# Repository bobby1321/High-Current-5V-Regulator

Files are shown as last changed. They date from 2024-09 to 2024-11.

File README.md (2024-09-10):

# High Current 5V DC Buck Converter Board
This board is a high current (8A) buck converter based around the TPS51386 for providing USB power to multiple devices from one board. Focused around working from a 4S Lithium Ion battery, it should work for any input voltage source from 10V-26V DC. The board also incorporates two INA219A PMICs for monitoring input & output power over I2C.

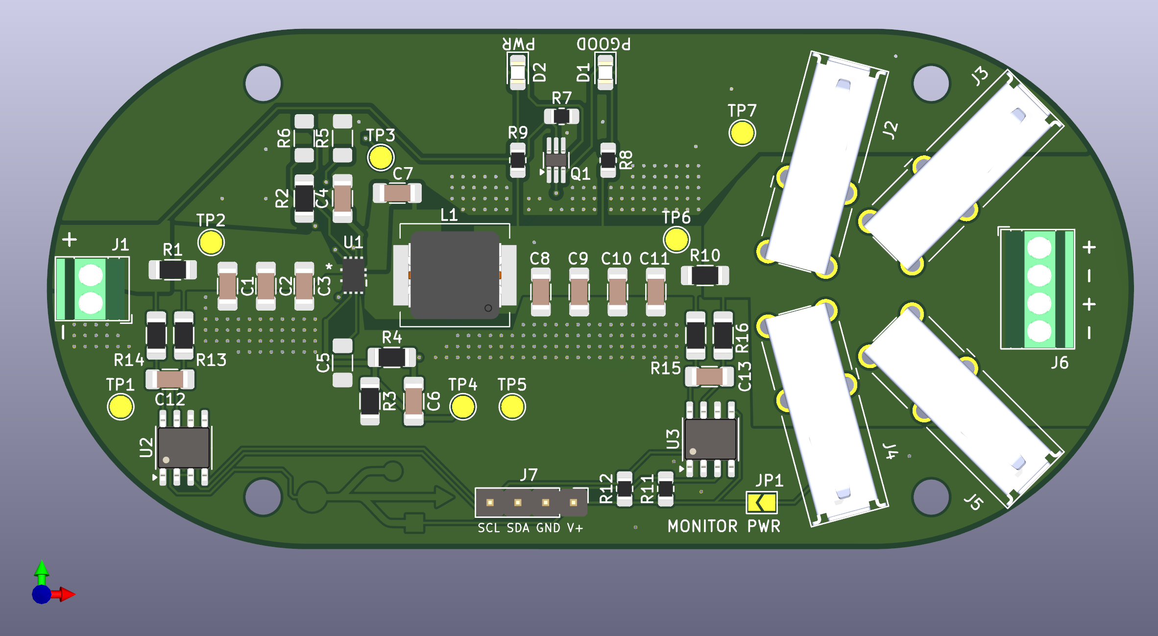
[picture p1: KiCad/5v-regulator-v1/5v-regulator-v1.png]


Also included in this repo is a small 4S Li-Ion battery voltage meter.

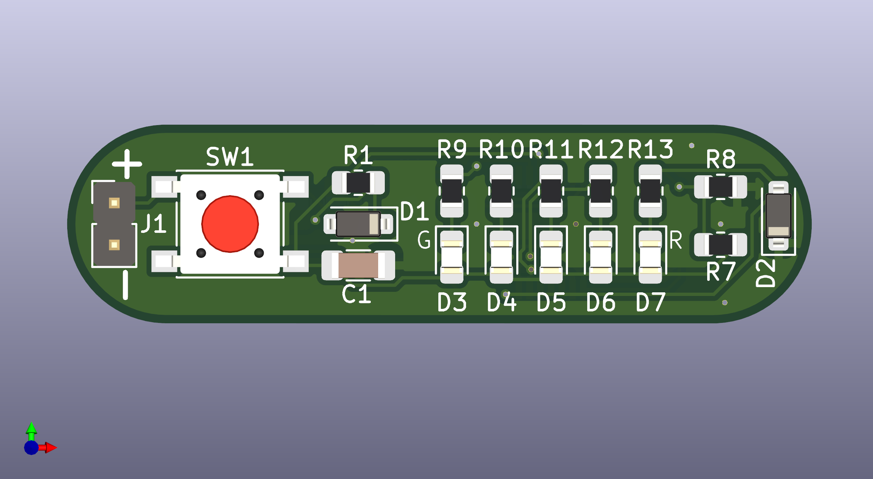
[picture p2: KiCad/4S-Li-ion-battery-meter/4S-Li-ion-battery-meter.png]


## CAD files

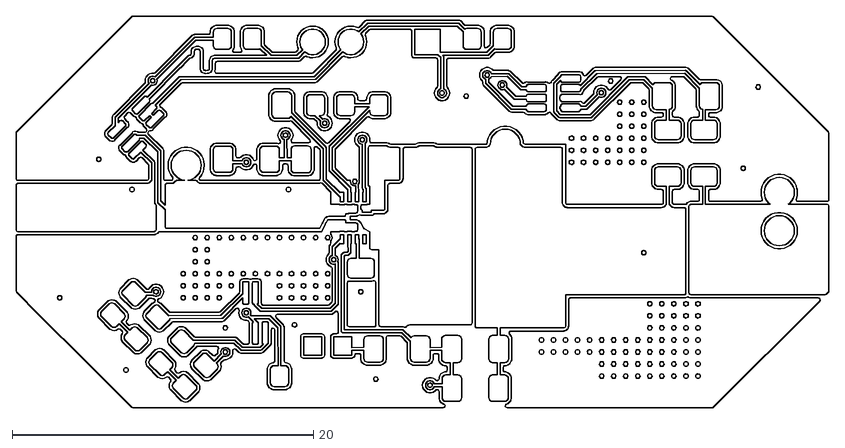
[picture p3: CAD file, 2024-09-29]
KiCad/5v-regulator-v2/5v-regulator-v2-F_Cu.dxf
54.0 x 26.0

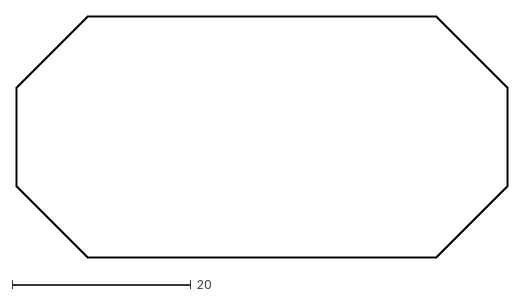
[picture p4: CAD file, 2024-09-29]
KiCad/5v-regulator-v2/5v-regulator-v2-Edge_Cuts.dxf
55.0 x 27.0

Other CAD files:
KiCad/5v-regulator-v2/5v-regulator-v2-F_Silkscreen.dxf

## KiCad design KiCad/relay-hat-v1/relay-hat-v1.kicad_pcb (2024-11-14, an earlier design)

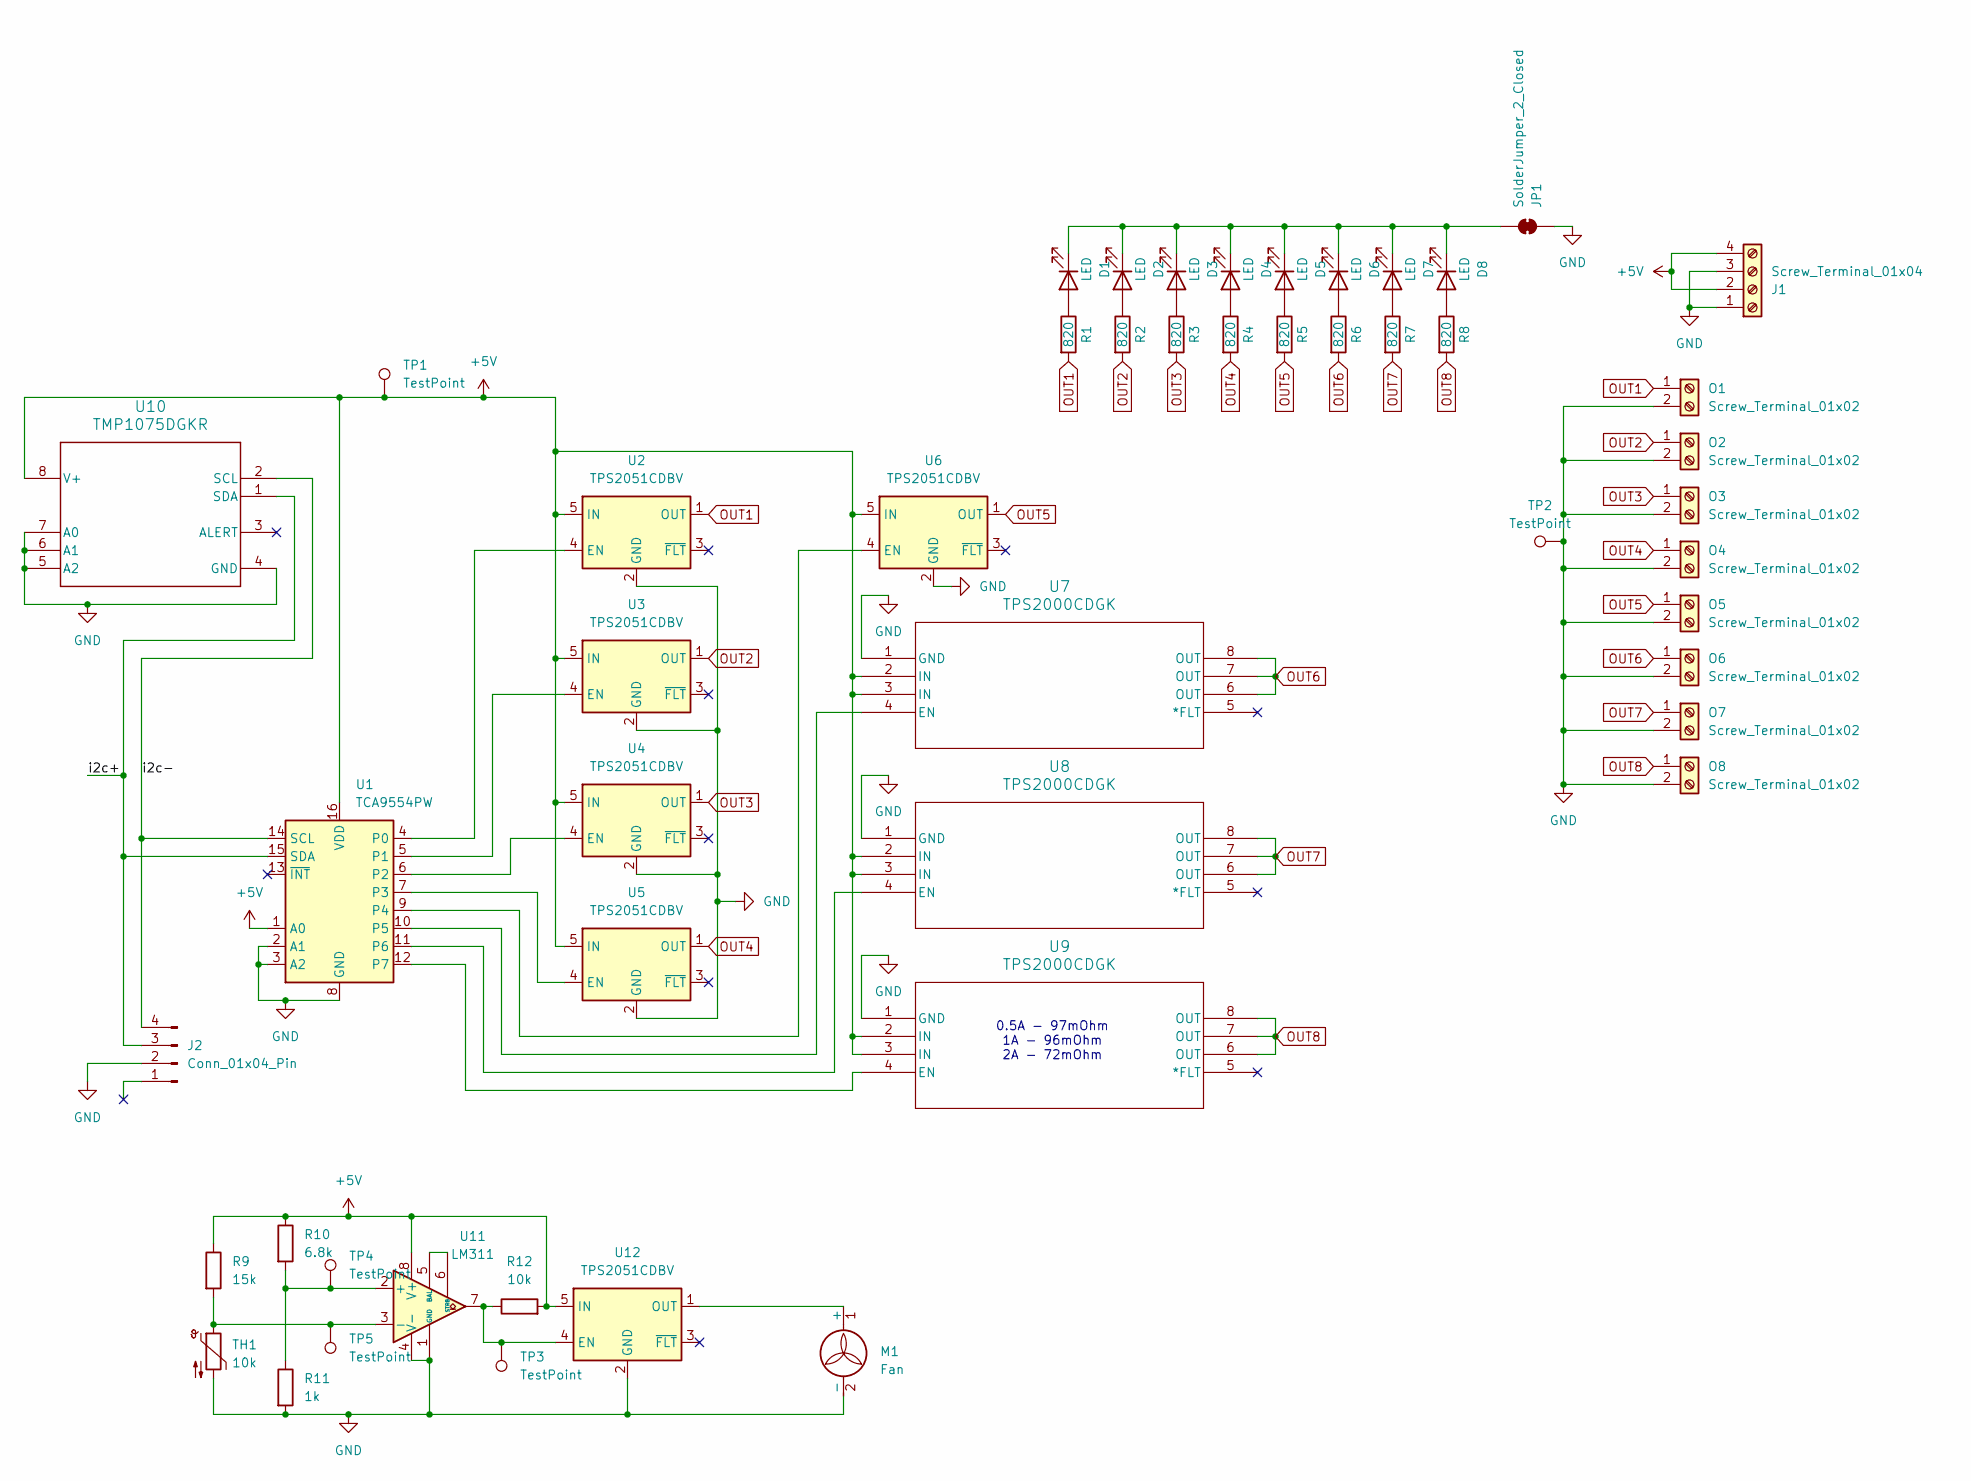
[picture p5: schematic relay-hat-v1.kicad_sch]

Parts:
D1, D2, D3, D4, D5, D6, D7, D8: LED; LED_0805_2012Metric_Pad1.15x1.40mm_HandSolder
J1: Screw_Terminal_01x04; TerminalBlock_Phoenix_MPT-0,5-4-2.54_1x04_P2.54mm_Horizontal
J2: Conn_01x04_Pin; PinHeader_1x04_P2.54mm_Vertical
JP1: SolderJumper_2_Closed; SolderJumper-2_P1.3mm_Open_TrianglePad1.0x1.5mm
M1: Fan; JST_XH_B2B-XH-A_1x02_P2.50mm_Vertical
O1, O2, O3, O4, O5, O6, O7, O8: Screw_Terminal_01x02; TerminalBlock_Phoenix_MPT-0,5-2-2.54_1x02_P2.54mm_Horizontal
R1, R2, R3, R4, R5, R6, R7, R8: 820; R_0805_2012Metric_Pad1.20x1.40mm_HandSolder
R9: 15k; R_0805_2012Metric_Pad1.20x1.40mm_HandSolder
R10: 6.8k; R_0805_2012Metric_Pad1.20x1.40mm_HandSolder
R11: 1k; R_0805_2012Metric_Pad1.20x1.40mm_HandSolder
R12: 10k; R_0805_2012Metric_Pad1.20x1.40mm_HandSolder
TH1: 10k; JST_XH_B2B-XH-A_1x02_P2.50mm_Vertical
TP1, TP2, TP3, TP4, TP5: TestPoint; TestPoint_Pad_D1.0mm
U1: TCA9554PW; TSSOP-16_4.4x5mm_P0.65mm
U2, U3, U4, U5, U6, U12: TPS2051CDBV; SOT-23-5
U7, U8, U9: TPS2000CDGK; DGK8
U10: TMP1075DGKR; DGK0008A_N
U11: LM311; SOIC-8_3.9x4.9mm_P1.27mm

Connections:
+5V: J1.2, J1.4, R9.1, R10.1, R12.2, TP1.1, U1.1 (A0), U1.16 (VDD), U2.5 (IN), U3.5 (IN), U4.5 (IN), U5.5 (IN), U6.5 (IN), U7.2 (IN), U7.3 (IN), U8.2 (IN), U8.3 (IN), U9.2 (IN), U9.3 (IN), U10.8 (V+), U11.8 (V+), U12.5 (IN)
/i2c+: J2.3, U1.15 (SDA), U10.1 (SDA)
/i2c-: J2.4, U1.14 (SCL), U10.2 (SCL)
GND: J1.1, J1.3, J2.2, JP1.2 (B), M1.2 (-), O1.2, O2.2, O3.2, O4.2, O5.2, O6.2, O7.2, O8.2, R11.2, TH1.2, TP2.1, U1.2 (A1), U1.3 (A2), U1.8 (GND), U2.2 (GND), U3.2 (GND), U4.2 (GND), U5.2 (GND), U6.2 (GND), U7.1 (GND), U8.1 (GND), U9.1 (GND), U10.4 (GND), U10.5 (A2), U10.6 (A1), U10.7 (A0), U11.1 (GND), U11.4 (V-), U12.2 (GND)
unnamed: D1.2 (A), R1.1
unnamed: D1.1 (K), D2.1 (K), D3.1 (K), D4.1 (K), D5.1 (K), D6.1 (K), D7.1 (K), D8.1 (K), JP1.1 (A)
unnamed: D2.2 (A), R2.1
unnamed: D3.2 (A), R3.1
unnamed: D4.2 (A), R4.1
unnamed: D5.2 (A), R5.1
unnamed: D6.2 (A), R6.1
unnamed: D7.2 (A), R7.1
unnamed: D8.2 (A), R8.1
unnamed: M1.1 (+), U12.1 (OUT)
unnamed: U1.4 (P0), U2.4 (EN)
unnamed: U1.5 (P1), U3.4 (EN)
unnamed: U1.6 (P2), U4.4 (EN)
unnamed: U1.7 (P3), U5.4 (EN)
unnamed: U1.9 (P4), U6.4 (EN)
unnamed: U1.10 (P5), U7.4 (EN)
unnamed: U1.11 (P6), U8.4 (EN)
unnamed: U1.12 (P7), U9.4 (EN)
unnamed: R10.2, R11.1, TP4.1, U11.2 (+)
unnamed: R9.2, TH1.1, TP5.1, U11.3 (-)
unnamed: U11.5 (BAL), U11.6 (STRB)
unnamed: R12.1, TP3.1, U11.7, U12.4 (EN)
OUT1: O1.1, R1.2, U2.1 (OUT)
OUT2: O2.1, R2.2, U3.1 (OUT)
OUT3: O3.1, R3.2, U4.1 (OUT)
OUT4: O4.1, R4.2, U5.1 (OUT)
OUT5: O5.1, R5.2, U6.1 (OUT)
OUT6: O6.1, R6.2, U7.6 (OUT), U7.7 (OUT), U7.8 (OUT)
OUT7: O7.1, R7.2, U8.6 (OUT), U8.7 (OUT), U8.8 (OUT)
OUT8: O8.1, R8.2, U9.6 (OUT), U9.7 (OUT), U9.8 (OUT)

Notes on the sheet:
0.5A - 97mOhm 1A - 96mOhm 2A - 72mOhm

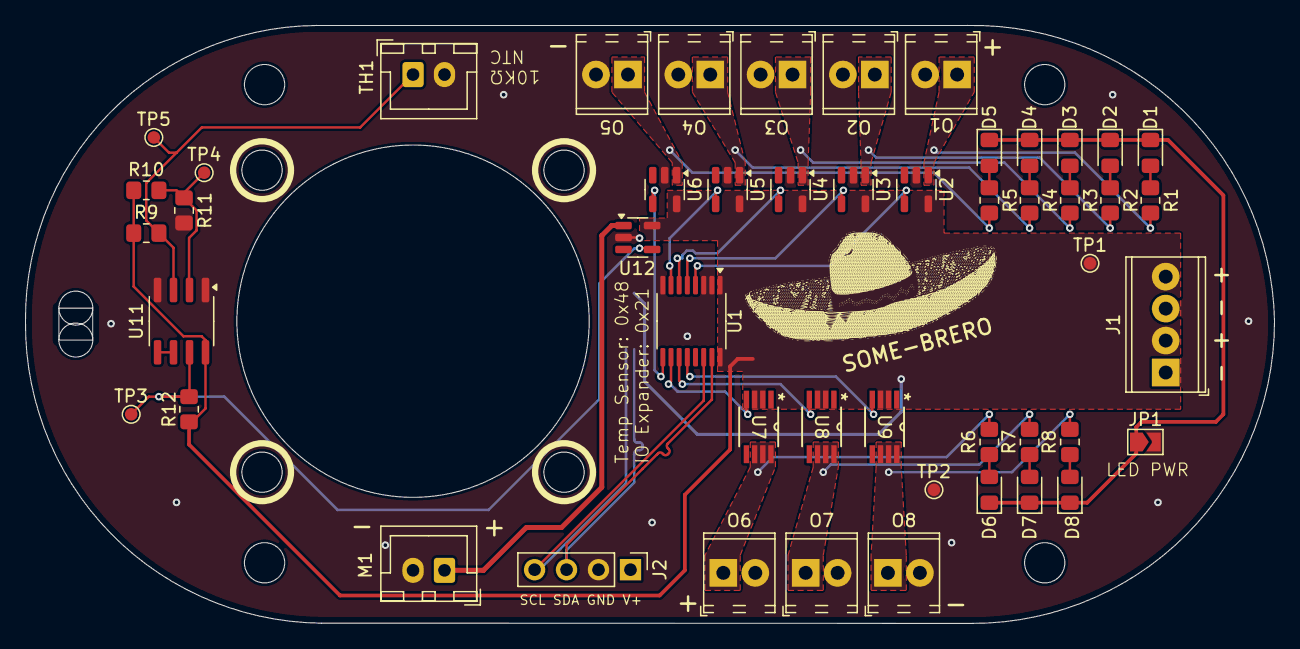
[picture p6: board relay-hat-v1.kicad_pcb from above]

Board: 2 copper layers, 99.3 x 47.5 mm, 50 parts (1 on the bottom side), 34 nets.

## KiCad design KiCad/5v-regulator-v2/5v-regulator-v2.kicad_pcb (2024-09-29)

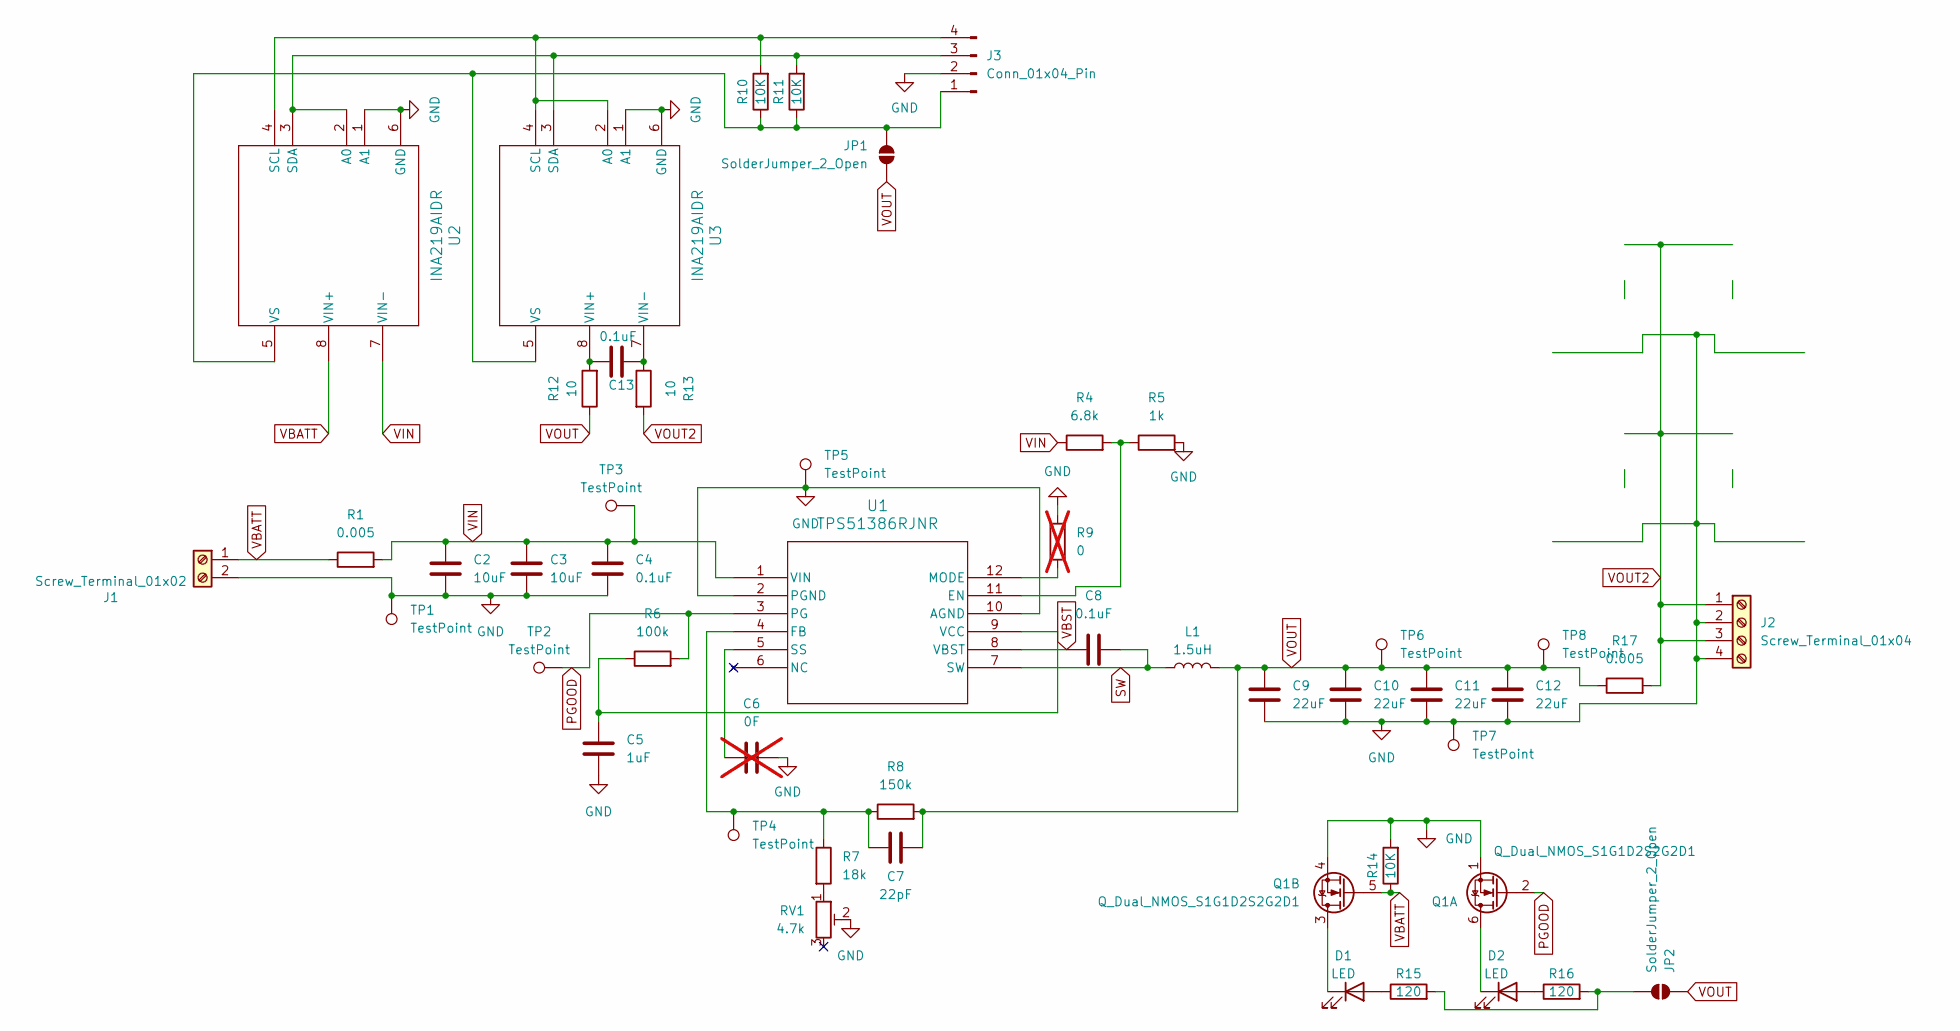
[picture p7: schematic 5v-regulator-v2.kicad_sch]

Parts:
C2, C3: 10uF; C_1206_3216Metric_Pad1.33x1.80mm_HandSolder
C4, C8, C13: 0.1uF; C_1206_3216Metric_Pad1.33x1.80mm_HandSolder
C5: 1uF; C_1206_3216Metric_Pad1.33x1.80mm_HandSolder
C6: 0F; C_1206_3216Metric_Pad1.33x1.80mm_HandSolder; not fitted
C7: 22pF; C_1206_3216Metric_Pad1.33x1.80mm_HandSolder
C9, C10, C11, C12: 22uF; C_1206_3216Metric_Pad1.33x1.80mm_HandSolder
D1, D2: LED; LED_0805_2012Metric_Pad1.15x1.40mm_HandSolder
J1: Screw_Terminal_01x02; TerminalBlock_Xinya_XY308-2.54-2P_1x02_P2.54mm_Horizontal
J2: Screw_Terminal_01x04; TerminalBlock_Xinya_XY308-2.54-4P_1x04_P2.54mm_Horizontal
J3: Conn_01x04_Pin; PinHeader_1x04_P2.54mm_Vertical
JP1, JP2: SolderJumper_2_Open; SolderJumper-2_P1.3mm_Open_TrianglePad1.0x1.5mm
L1: 1.5uH; L_Panasonic_ETQP4M---KVK
Q1: Q_Dual_NMOS_S1G1D2S2G2D1; SOT-363_SC-70-6_Handsoldering
R1, R17: 0.005; R_1206_3216Metric_Pad1.30x1.75mm_HandSolder
R4: 6.8k; R_0805_2012Metric_Pad1.20x1.40mm_HandSolder
R5: 1k; R_0805_2012Metric_Pad1.20x1.40mm_HandSolder
R6: 100k; R_1206_3216Metric_Pad1.30x1.75mm_HandSolder
R7: 18k; R_1206_3216Metric_Pad1.30x1.75mm_HandSolder
R8: 150k; R_1206_3216Metric_Pad1.30x1.75mm_HandSolder
R9: 0; R_1206_3216Metric_Pad1.30x1.75mm_HandSolder; not fitted
R10, R11, R14: 10K; R_0805_2012Metric_Pad1.20x1.40mm_HandSolder
R12, R13: 10; R_1206_3216Metric_Pad1.30x1.75mm_HandSolder
R15, R16: 120; R_0805_2012Metric_Pad1.20x1.40mm_HandSolder
RV1: 4.7k; Potentiometer_Bourns_TC33X_Vertical
TP1, TP2, TP3, TP4, TP5, TP6, TP7: TestPoint; TestPoint_Pad_D2.0mm
TP8: TestPoint; usb_symbol
U1: TPS51386RJNR; VQFN-HR12_RJN_TEX
U2, U3: INA219AIDR; SOT-23-8

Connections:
GND: C2.2, C3.2, C4.2, C5.2, C6.2, C9.2, C10.2, C11.2, C12.2, J1.2, J2.2, J2.4, J3.2, Q1.1 (S), Q1.4 (S), R5.2, R9.2, R14.2, RV1.2, TP1.1, TP5.1, TP7.1, U1.2 (PGND), U1.10 (AGND), U2.1 (A1), U2.6 (GND), U3.1 (A1), U3.6 (GND)
unnamed: D1.2 (A), R15.1
unnamed: D1.1 (K), Q1.3 (D)
unnamed: D2.2 (A), R16.1
unnamed: D2.1 (K), Q1.6 (D)
unnamed: J3.1, JP1.2 (B), R10.1, R11.1, U2.5 (VS), U3.5 (VS)
unnamed: J3.3, R11.2, U2.2 (A0), U2.3 (SDA), U3.3 (SDA)
unnamed: J3.4, R10.2, U2.4 (SCL), U3.2 (A0), U3.4 (SCL)
unnamed: JP2.1 (A), R15.2, R16.2
unnamed: R7.2, RV1.1
unnamed: R4.2, R5.1, U1.11 (EN)
unnamed: C7.2, R7.1, R8.1, TP4.1, U1.4 (FB)
unnamed: R9.1, U1.12 (MODE)
unnamed: C6.1, U1.5 (SS)
unnamed: C5.1, R6.1, U1.9 (VCC)
unnamed: C13.2, R12.2, U3.8 (VIN+)
unnamed: C13.1, R13.1, U3.7 (VIN-)
PGOOD: Q1.2 (G), R6.2, TP2.1, U1.3 (PG)
SW: C8.2, L1.1, U1.7 (SW)
VBATT: J1.1, Q1.5 (G), R1.1, R14.1, U2.8 (VIN+)
VBST: C8.1, U1.8 (VBST)
VIN: C2.1, C3.1, C4.1, R1.2, R4.1, TP3.1, U1.1 (VIN), U2.7 (VIN-)
VOUT: C7.1, C9.1, C10.1, C11.1, C12.1, JP1.1 (A), JP2.2 (B), L1.2, R8.2, R12.1, R17.1, TP6.1, TP8.1
VOUT2: J2.1, J2.3, R13.2, R17.2

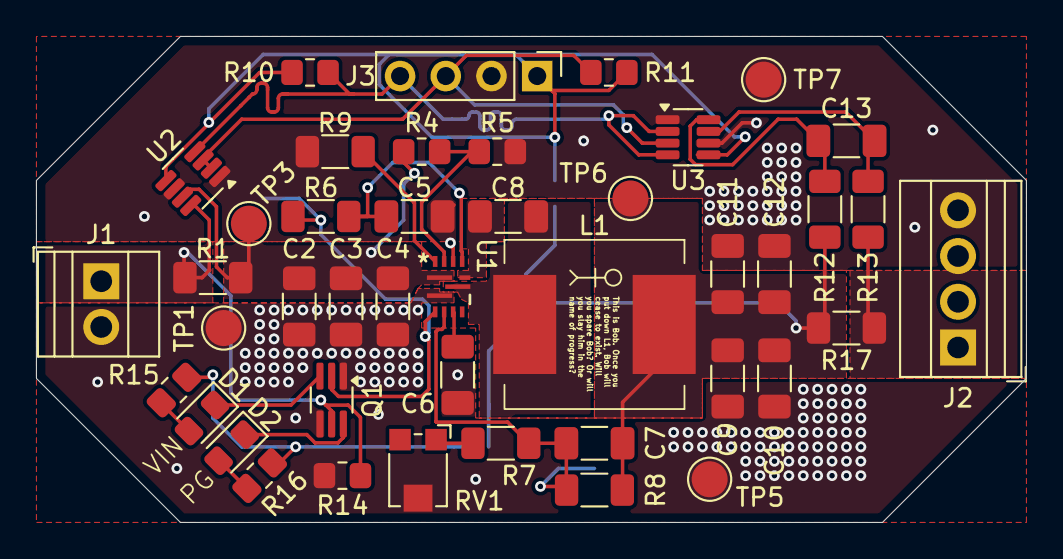
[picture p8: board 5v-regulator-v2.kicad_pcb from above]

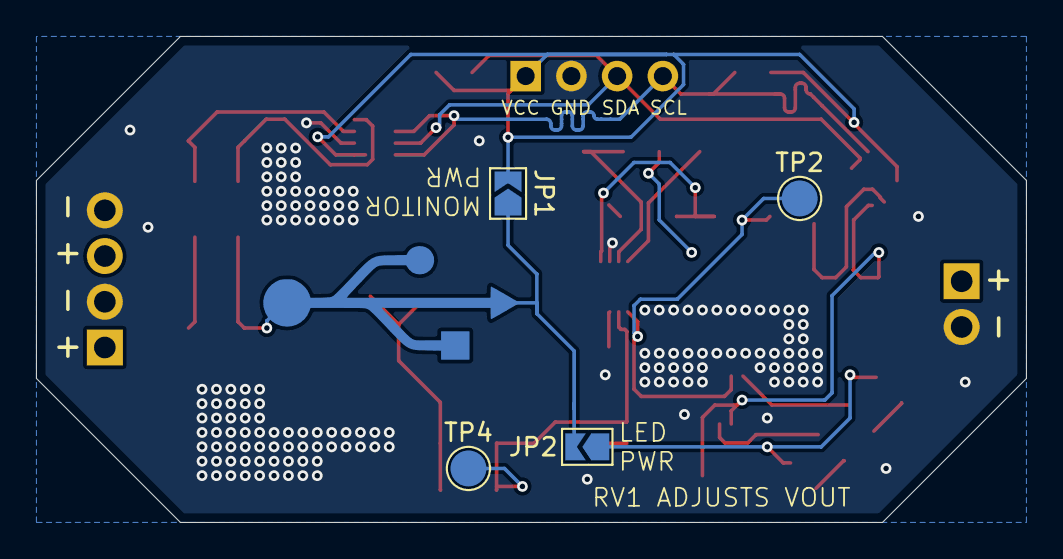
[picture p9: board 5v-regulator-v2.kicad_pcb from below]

Board: 2 copper layers, 55.0 x 27.0 mm, 48 parts (5 on the bottom side), 24 nets.

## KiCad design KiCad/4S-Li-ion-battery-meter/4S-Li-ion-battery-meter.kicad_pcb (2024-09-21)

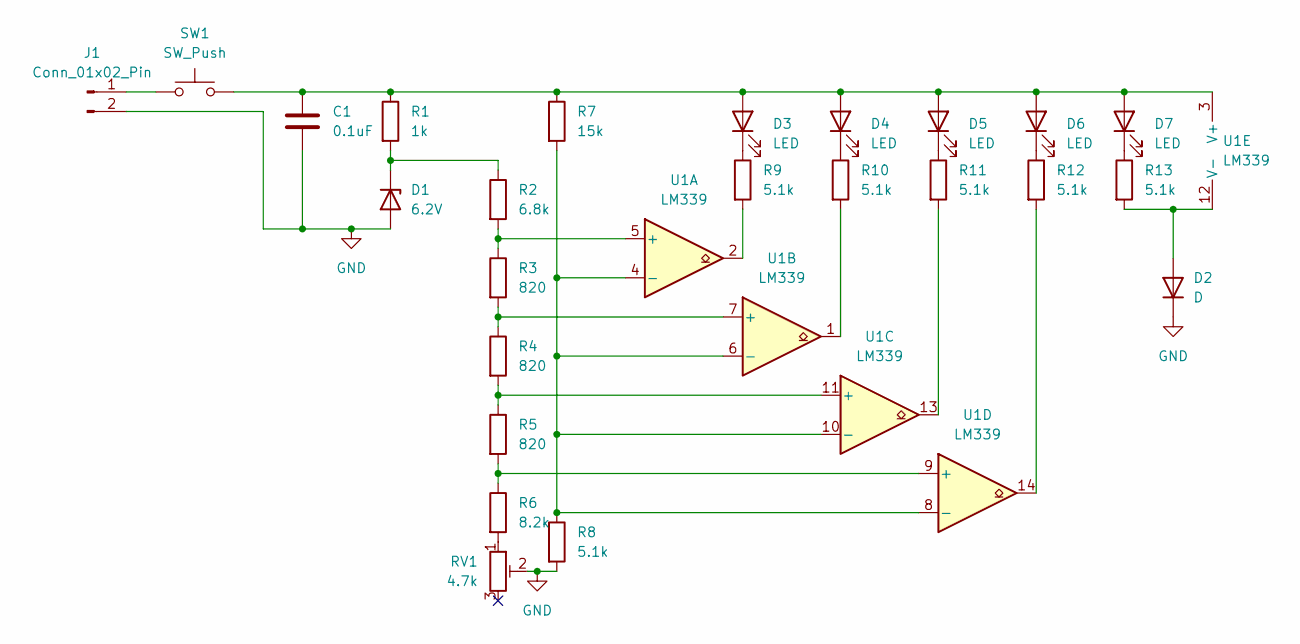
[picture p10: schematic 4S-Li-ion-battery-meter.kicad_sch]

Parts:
C1: 0.1uF; C_1206_3216Metric_Pad1.33x1.80mm_HandSolder
D1: 6.2V; D_SOD-123
D2: D; D_SOD-123
D3, D4, D5, D6, D7: LED; LED_0805_2012Metric_Pad1.15x1.40mm_HandSolder
J1: Conn_01x02_Pin; PinHeader_1x02_P2.54mm_Vertical
R1: 1k; R_0805_2012Metric_Pad1.20x1.40mm_HandSolder
R2: 6.8k; R_0805_2012Metric_Pad1.20x1.40mm_HandSolder
R3, R4, R5: 820; R_0805_2012Metric_Pad1.20x1.40mm_HandSolder
R6: 8.2k; R_0805_2012Metric_Pad1.20x1.40mm_HandSolder
R7: 15k; R_0805_2012Metric_Pad1.20x1.40mm_HandSolder
R8, R9, R10, R11, R12, R13: 5.1k; R_0805_2012Metric_Pad1.20x1.40mm_HandSolder
RV1: 4.7k; Potentiometer_Bourns_TC33X_Vertical
SW1: SW_Push; SW_Push_1P1T_NO_6x6mm_H9.5mm
U1: LM339; SSOP-14_5.3x6.2mm_P0.65mm

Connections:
GND: C1.2, D1.2 (A), D2.1 (K), J1.2, R8.2, RV1.2
unnamed: D1.1 (K), R1.2, R2.1
unnamed: D2.2 (A), R13.2, U1.12 (V-)
unnamed: C1.1, D3.2 (A), D4.2 (A), D5.2 (A), D6.2 (A), D7.2 (A), R1.1, R7.1, SW1.2, U1.3 (V+)
unnamed: D3.1 (K), R9.1
unnamed: D4.1 (K), R10.1
unnamed: D5.1 (K), R11.1
unnamed: D6.1 (K), R12.1
unnamed: D7.1 (K), R13.1
unnamed: J1.1, SW1.1
unnamed: R6.2, RV1.1
unnamed: R9.2, U1.2
unnamed: R10.2, U1.1
unnamed: R11.2, U1.13
unnamed: R12.2, U1.14
unnamed: R2.2, R3.1, U1.5 (+)
unnamed: R7.2, R8.1, U1.4 (-), U1.6 (-), U1.8 (-), U1.10 (-)
unnamed: R3.2, R4.1, U1.7 (+)
unnamed: R4.2, R5.1, U1.11 (+)
unnamed: R5.2, R6.1, U1.9 (+)

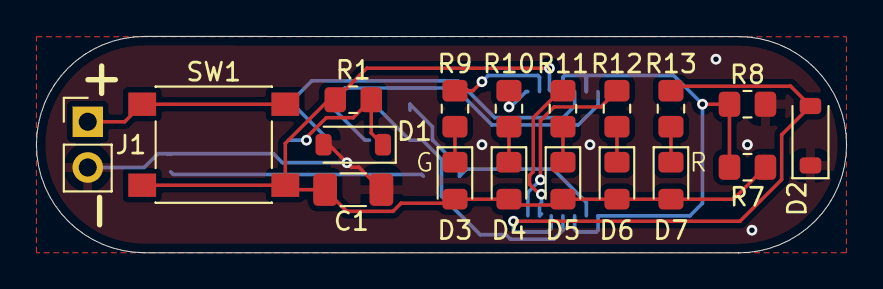
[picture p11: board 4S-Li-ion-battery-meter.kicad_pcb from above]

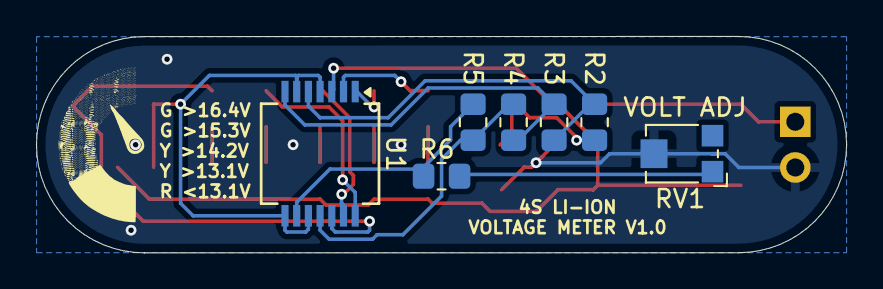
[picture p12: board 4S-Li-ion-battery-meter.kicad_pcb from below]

Board: 2 copper layers, 45.0 x 12.0 mm, 25 parts (7 on the bottom side), 20 nets.

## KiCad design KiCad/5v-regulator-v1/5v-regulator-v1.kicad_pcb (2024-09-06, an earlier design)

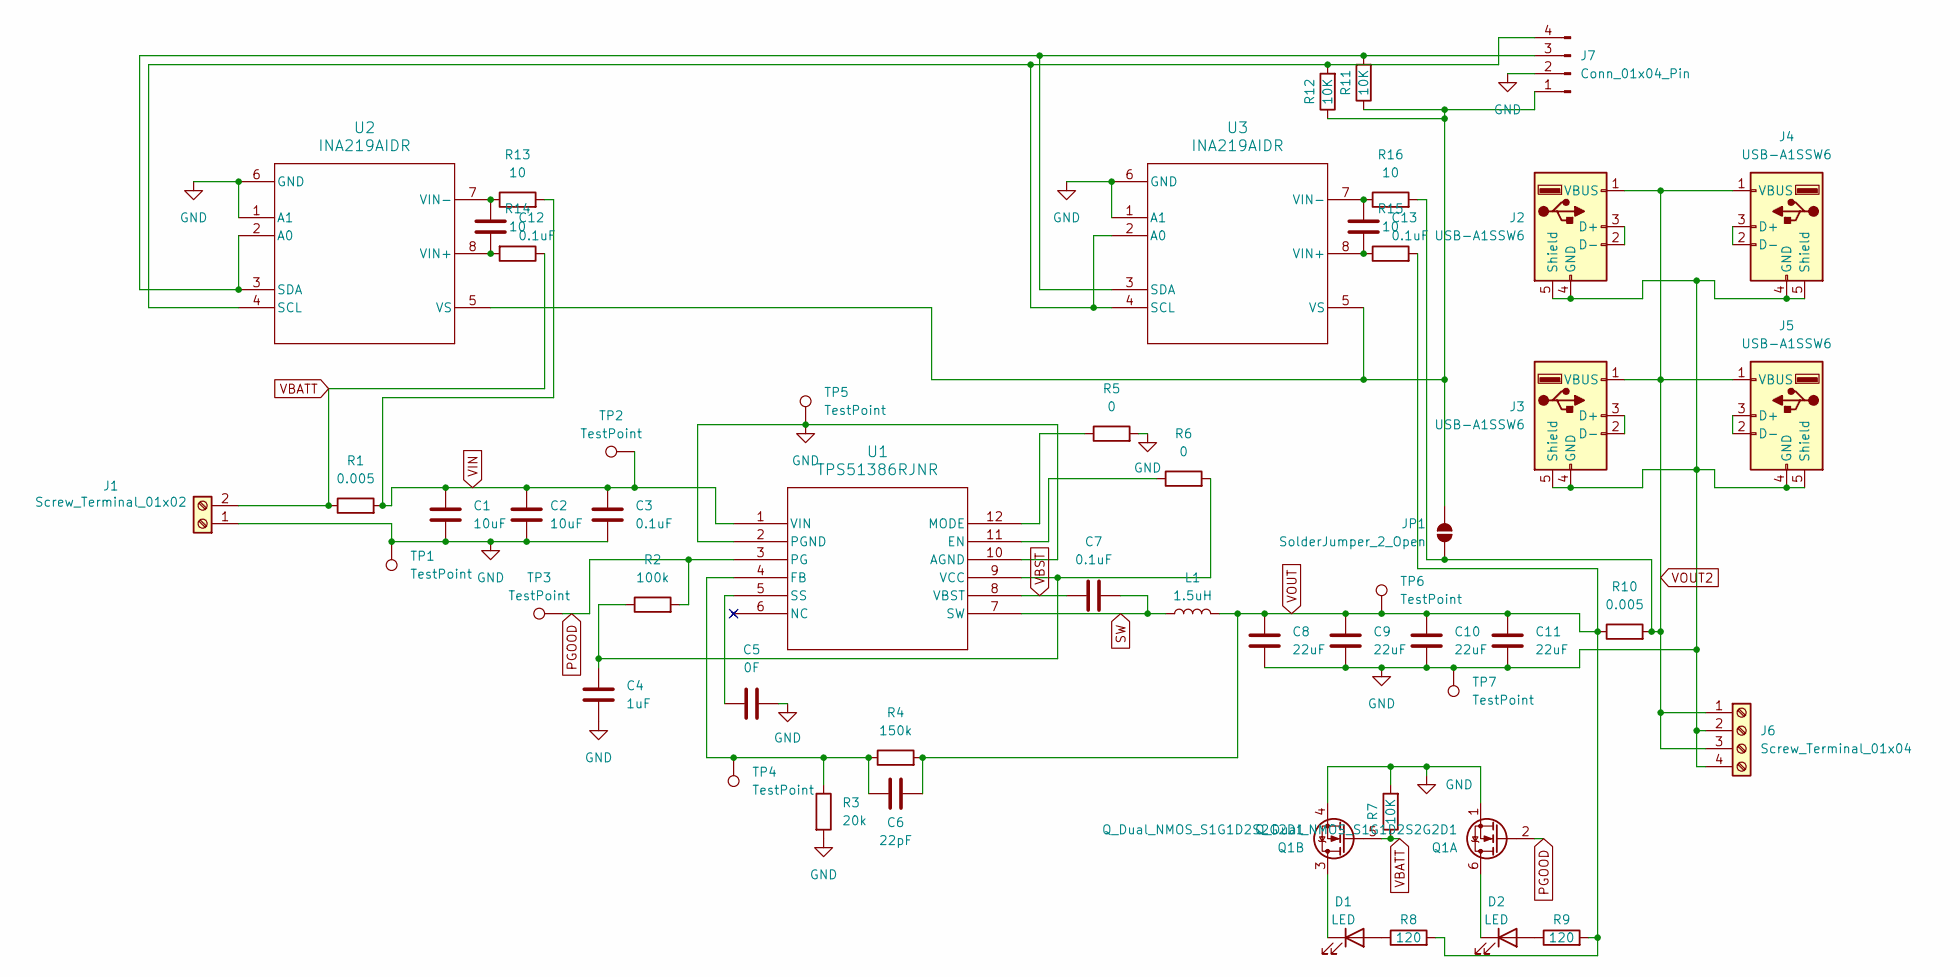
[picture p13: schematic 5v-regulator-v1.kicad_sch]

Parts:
C1, C2: 10uF; C_1206_3216Metric_Pad1.33x1.80mm_HandSolder
C3, C7, C12, C13: 0.1uF; C_1206_3216Metric_Pad1.33x1.80mm_HandSolder
C4: 1uF; C_1206_3216Metric_Pad1.33x1.80mm_HandSolder
C5: 0F; C_1206_3216Metric_Pad1.33x1.80mm_HandSolder
C6: 22pF; C_1206_3216Metric_Pad1.33x1.80mm_HandSolder
C8, C9, C10, C11: 22uF; C_1206_3216Metric_Pad1.33x1.80mm_HandSolder
D1, D2: LED; LED_0805_2012Metric_Pad1.15x1.40mm_HandSolder
J1: Screw_Terminal_01x02; TerminalBlock_Xinya_XY308-2.54-2P_1x02_P2.54mm_Horizontal
J2, J3, J4, J5: USB-A1SSW6; USB_A_Wuerth_614004134726_Horizontal; PARTREV A
J6: Screw_Terminal_01x04; TerminalBlock_Xinya_XY308-2.54-4P_1x04_P2.54mm_Horizontal
J7: Conn_01x04_Pin; PinHeader_1x04_P2.54mm_Vertical
JP1: SolderJumper_2_Open; SolderJumper-2_P1.3mm_Open_TrianglePad1.0x1.5mm
L1: 1.5uH; IND_WE-LHMI_8030_WRE
Q1: Q_Dual_NMOS_S1G1D2S2G2D1; SOT-363_SC-70-6_Handsoldering
R1, R10: 0.005; R_1206_3216Metric_Pad1.30x1.75mm_HandSolder
R2: 100k; R_1206_3216Metric_Pad1.30x1.75mm_HandSolder
R3: 20k; R_1206_3216Metric_Pad1.30x1.75mm_HandSolder
R4: 150k; R_1206_3216Metric_Pad1.30x1.75mm_HandSolder
R5, R6: 0; R_1206_3216Metric_Pad1.30x1.75mm_HandSolder
R7, R11, R12: 10K; R_0805_2012Metric_Pad1.20x1.40mm_HandSolder
R8, R9: 120; R_0805_2012Metric_Pad1.20x1.40mm_HandSolder
R13, R14, R15, R16: 10; R_1206_3216Metric_Pad1.30x1.75mm_HandSolder
TP1, TP2, TP3, TP4, TP5, TP6, TP7: TestPoint; TestPoint_Pad_D2.0mm
U1: TPS51386RJNR; VQFN-HR12_RJN_TEX
U2, U3: INA219AIDR; SOIC-8_3.9x4.9mm_P1.27mm

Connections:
GND: C1.2, C2.2, C3.2, C4.2, C5.2, C8.2, C9.2, C10.2, C11.2, J1.1, J2.4 (GND), J2.5 (Shield), J3.4 (GND), J3.5 (Shield), J4.4 (GND), J4.5 (Shield), J5.4 (GND), J5.5 (Shield), J6.2, J6.4, J7.2, Q1.1 (S), Q1.4 (S), R3.2, R5.2, R7.2, TP1.1, TP5.1, TP7.1, U1.2 (PGND), U1.10 (AGND), U2.1 (A1), U2.6 (GND), U3.1 (A1), U3.6 (GND)
unnamed: D1.2 (A), R8.1
unnamed: D1.1 (K), Q1.3 (D)
unnamed: D2.2 (A), R9.1
unnamed: D2.1 (K), Q1.6 (D)
unnamed: J2.2 (D-), J2.3 (D+)
unnamed: J3.2 (D-), J3.3 (D+)
unnamed: J4.2 (D-), J4.3 (D+)
unnamed: J5.2 (D-), J5.3 (D+)
unnamed: J7.1, JP1.2 (B), R11.1, R12.1, U2.5 (VS), U3.5 (VS)
unnamed: J7.3, R11.2, U2.2 (A0), U2.3 (SDA), U3.3 (SDA)
unnamed: J7.4, R12.2, U2.4 (SCL), U3.2 (A0), U3.4 (SCL)
unnamed: R6.1, U1.11 (EN)
unnamed: C6.2, R3.1, R4.1, TP4.1, U1.4 (FB)
unnamed: R5.1, U1.12 (MODE)
unnamed: C5.1, U1.5 (SS)
unnamed: C4.1, R2.1, R6.2, U1.9 (VCC)
unnamed: C12.2, R14.2, U2.8 (VIN+)
unnamed: C12.1, R13.1, U2.7 (VIN-)
unnamed: C13.2, R15.1, U3.8 (VIN+)
unnamed: C13.1, R16.1, U3.7 (VIN-)
PGOOD: Q1.2 (G), R2.2, TP3.1, U1.3 (PG)
SW: C7.2, L1.1, U1.7 (SW)
VBATT: J1.2, Q1.5 (G), R1.1, R7.1, R14.1
VBST: C7.1, U1.8 (VBST)
VIN: C1.1, C2.1, C3.1, R1.2, R13.2, TP2.1, U1.1 (VIN)
VOUT: C6.1, C8.1, C9.1, C10.1, C11.1, L1.2, R4.2, R8.2, R9.2, R10.1, R15.2, TP6.1
VOUT2: J2.1 (VBUS), J3.1 (VBUS), J4.1 (VBUS), J5.1 (VBUS), J6.1, J6.3, JP1.1 (A), R10.2, R16.2

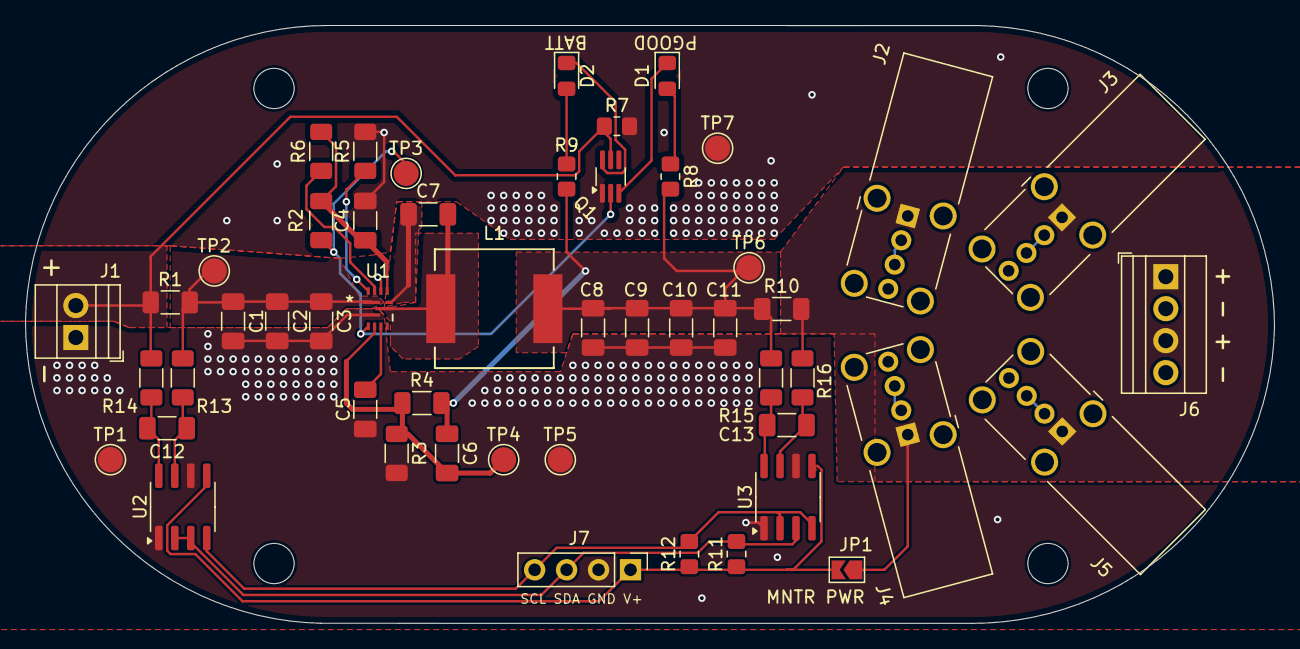
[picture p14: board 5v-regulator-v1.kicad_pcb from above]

Board: 2 copper layers, 99.3 x 47.5 mm, 51 parts (0 on the bottom side), 28 nets.

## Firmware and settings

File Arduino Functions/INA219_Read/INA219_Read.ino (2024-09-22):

//
//    FILE: INA219_array.ino
//  AUTHOR: Rob Tillaart
// PURPOSE: demo array of INA219 sensors
//     URL: https://github.com/RobTillaart/INA219


#include "INA219.h"

INA219 arr_ina[2] = { INA219(0x42), INA219(0x43) };
String incomingString = "";  // for incoming serial data

void setup() {
  Serial.begin(115200);
  // Serial.println(__FILE__);
  // Serial.print("INA219_LIB_VERSION: ");
  // Serial.println(INA219_LIB_VERSION);

  Wire.begin();

  for (int i = 0; i < 2; i++) {
    if (!arr_ina[i].begin()) {
      Serial.print("Could not connect:  ");
      Serial.print(i);
      Serial.println(". Fix and Reboot");
    }
  }

  for (int i = 0; i < 2; i++) {
    arr_ina[i].setMaxCurrentShunt(10, 0.005);
    arr_ina[i].setBusVoltageRange(32);
    arr_ina[i].setGain(2);
    arr_ina[i].setShuntADC(0xB);
    delay(1000);
    // Serial.println(arr_ina[i].getBusVoltageRange());
  }
}


void loop() {

  if (Serial.available() > 0) {
    // read the incoming byte:
    incomingString = Serial.readString();
    incomingString.trim();

    if (incomingString == "read") {
      // Serial.println("\n\t#\tBUS(V)\t\tSHUNT(mV)\tCURRENT(mA)\tPOWER(mW)\tOVF\t\tCNVR");
      for (int i = 0; i < 2; i++) {
        // Serial.print("\t");
        // Serial.print(i);
        // Serial.print("\t");
        Serial.print(arr_ina[i].getBusVoltage(), 4);
        Serial.print(" ");
        // Serial.print(arr_ina[i].getShuntVoltage_mV(), 4);
        // Serial.print(" ");
        Serial.print(arr_ina[i].getCurrent_mA(), 4);
        Serial.print(" ");
        Serial.print(arr_ina[i].getPower_mW(), 4);
        // Serial.print(" ");
        // Serial.print(arr_ina[i].getMathOverflowFlag());
        // Serial.print("\t\t");
        // Serial.print(arr_ina[i].getConversionFlag());
        Serial.println();
      }
    }
  }
}


  //  -- END OF FILE --

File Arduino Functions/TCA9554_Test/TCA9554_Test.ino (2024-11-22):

#include <Wire.h>

void setup() {
  Serial.begin(115200);
  Wire.begin();
  delay(100);
  Wire.beginTransmission(33);
  Wire.write(3);
  Wire.write(255); // 0 to 255 for each channel
  Serial.println(String(Wire.endTransmission()));
  delay(100);
  Wire.beginTransmission(33);
  Wire.write(1);
  Wire.write(0);
  Serial.println(String(Wire.endTransmission()));
}

void loop() {
  
  // for (int pin = 0; pin < 8; pin++) {
  //   Wire.beginTransmission(33);;
  //   Wire.write(1);
  //   Wire.write(1<<pin);
  //   Wire.endTransmission();
  //   delay(100);
  // }
  Wire.beginTransmission(33);
  int output_reg;
  Wire.write(1);
    
  Wire.requestFrom(33, 1);
  while (Wire.available()) 
  {                                   
    output_reg = Wire.read();
    // output_reg = 0;
    // Serial.println(String(output_reg));
  }
  Serial.println(String(output_reg));
  Serial.println(String(Wire.endTransmission()));
  delay(100);
}

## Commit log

2024-08-31 Updated PCB design
    [5v-regulator-v1.kicad_pcb]
2024-08-31 Changed resistor values
2024-09-02 Blaine review
    [5v-regulator-v1.kicad_pcb, 5v-regulator-v1.kicad_sch]
2024-09-06 Updated 5V reg and added battery meter
    [4S-Li-ion-battery-meter.kicad_pcb, 4S-Li-ion-battery-meter.kicad_sch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]
2024-09-08 Sent to production!
    [4S-Li-ion-battery-meter.kicad_pcb, 4S-Li-ion-battery-meter.kicad_sch, 5v-regulator-v1.kicad_sch]
2024-09-21 Fixed errors (missing enable & overlapping trace)
    I should really RTFM and run the DRC...
    [4S-Li-ion-battery-meter.kicad_pcb, 5v-regulator-v1.kicad_sch]
2024-09-21 Added solder pad for LEDs
    [5v-regulator-v1.kicad_sch]
2024-09-21 v2 smaller board
    [5v-regulator-v2.kicad_pcb, 5v-regulator-v2.kicad_sch]
2024-09-29 Added relay hats!
    Version 1 & version 2 have different version hats, but the versions are not compatible between version 1 and version 2 or vice versa
    [5v-regulator-v2-Edge_Cuts.dxf, 5v-regulator-v2-F_Cu.dxf, 5v-regulator-v2-F_Silkscreen.dxf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]
2024-09-29 Updated some silkscreen
    [5v-regulator-v2.kicad_pcb]
2024-11-14 Test code and changed diode for resistor
    The diode after the op-amp on the relay board is now a 10K pullup resistor
    [relay-hat-v1.kicad_pcb, relay-hat-v1.kicad_sch]
2024-11-22 Updated some code and micro-some-brero
    [relay-hat-v1.kicad_sch, relay-hat-v2.kicad_sch]
2025-01-10 Increased pitch of terminal blocks to fit ferrules
    [5v-regulator-v1.kicad_sch]
2025-01-11 Added input fuse and switched to stacked USBs
    [5v-regulator-v1.kicad_sch]
2025-02-14 Updated battery meter with 2S values
    Need to figure out a good way to automatically calculate resistor values based on input voltages...
    [5v-regulator-v1.kicad_sch]
